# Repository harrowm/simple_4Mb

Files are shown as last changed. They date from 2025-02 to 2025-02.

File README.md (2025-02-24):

# simple_4Mb
A simple 4Mb RAM expansion card for the rosco sac.  Complicated only by the fact its mainly SMT ...

24th Feb 2025

The boards are back from jlcpcb.  The only potential issue is that I put the vias for the capacitors on the pad.  This seems to have worked by default without the expensive via in pad process.  The connections between the pads and VCC/GND check out ok.
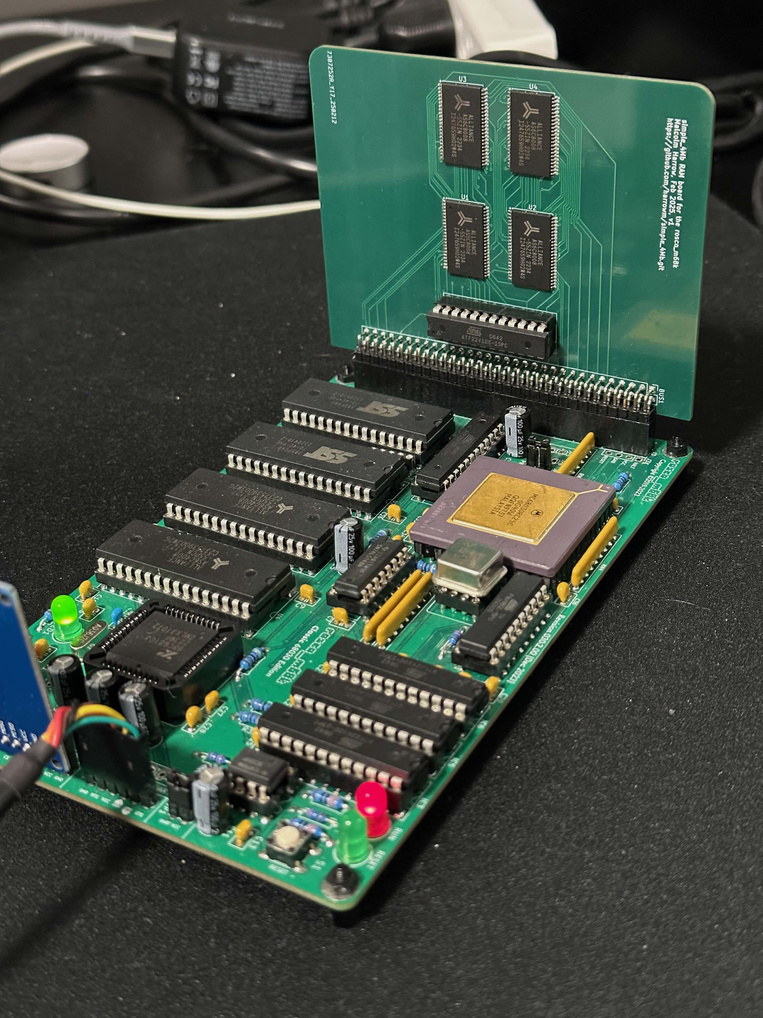
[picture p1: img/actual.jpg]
actual board


Running on the 68030 rosco works fine!
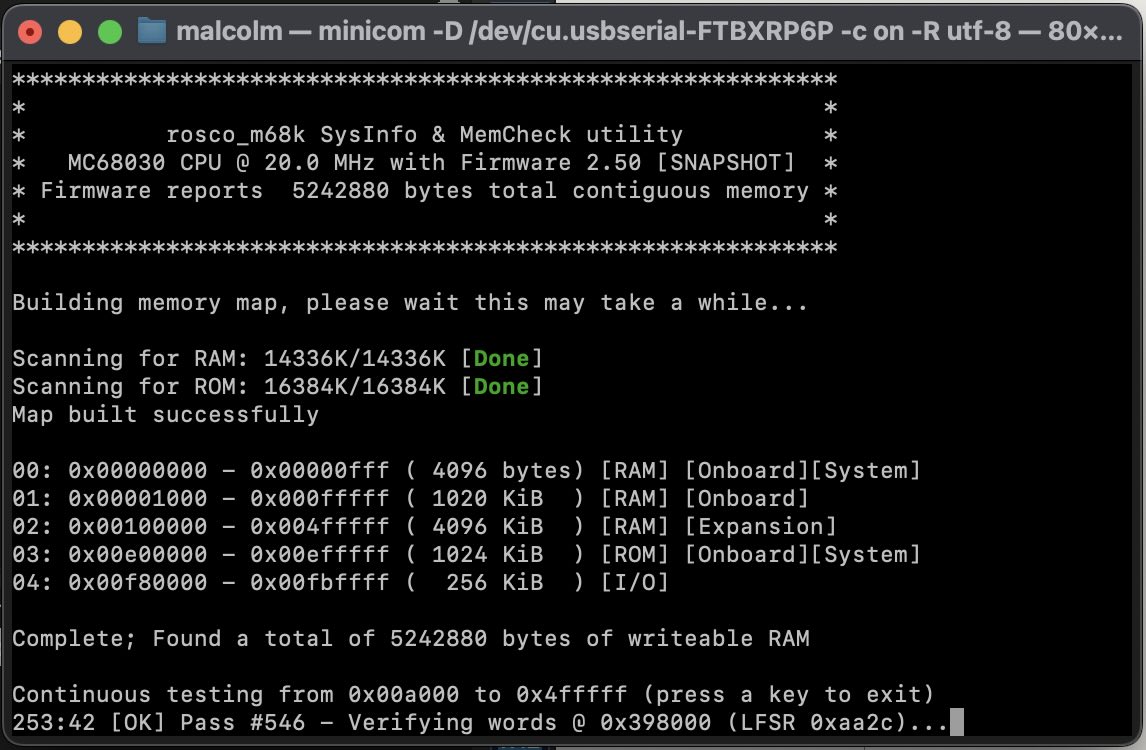
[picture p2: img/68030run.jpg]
running on the 68030


.. but the board is struggling on the 68010, not sure why ?
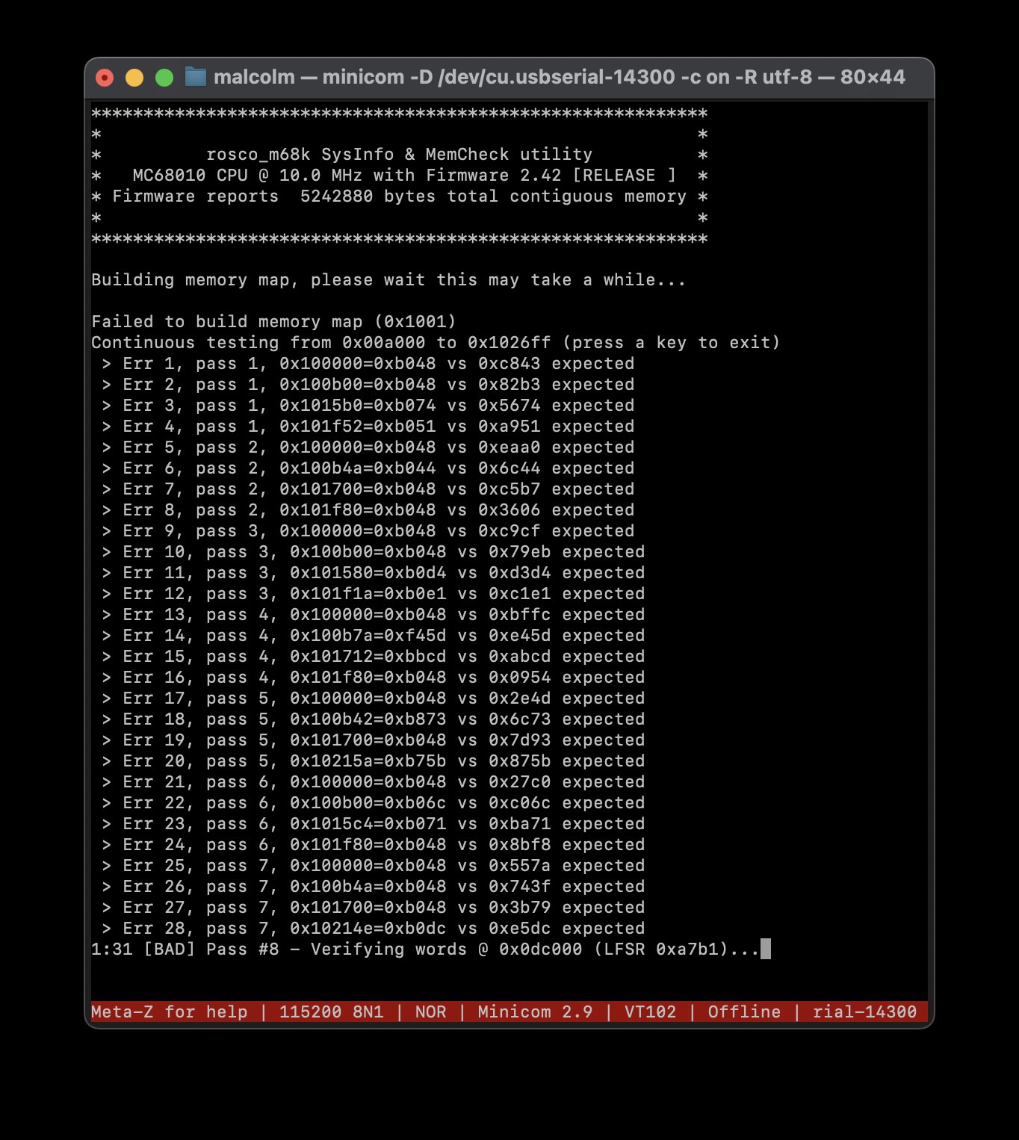
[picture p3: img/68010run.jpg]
running on the 68010


11th Feb 2025 - Sent to jlcpcb

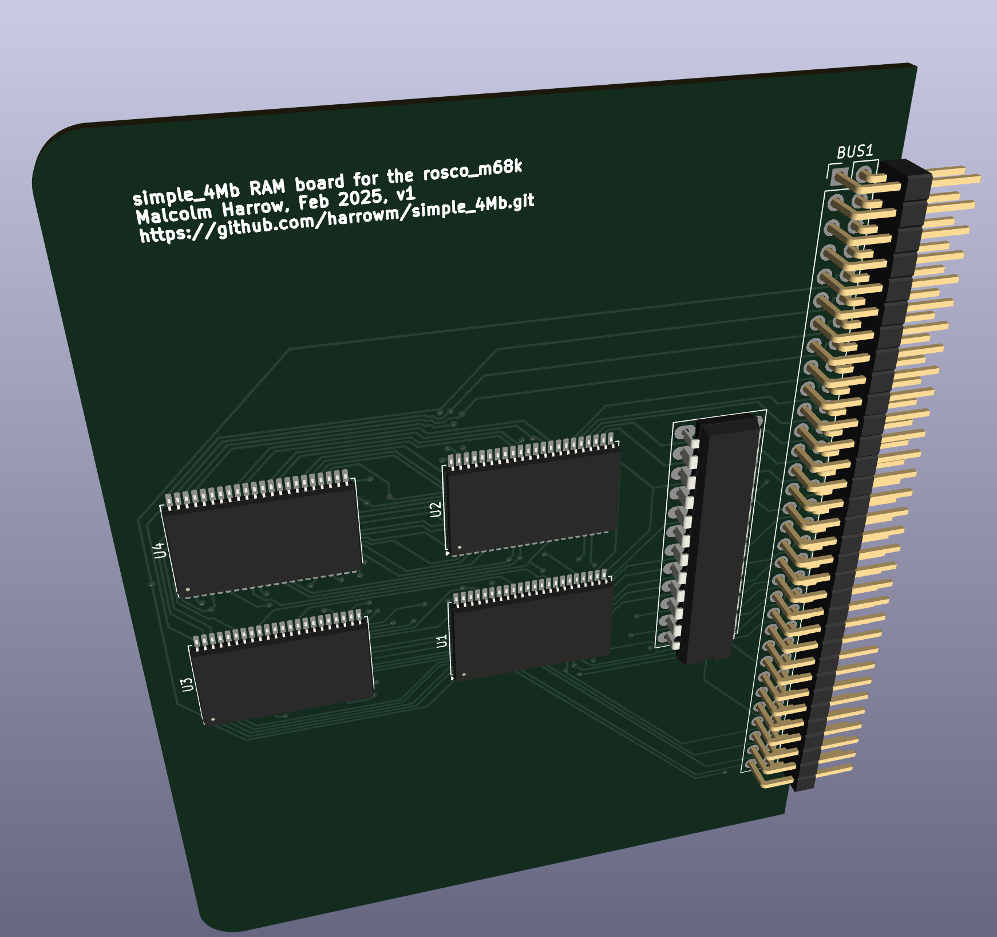
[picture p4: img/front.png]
3d model of board - front

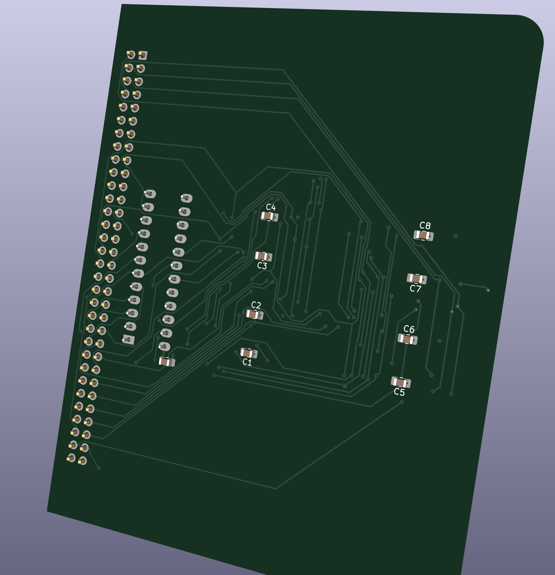
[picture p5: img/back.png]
3d model of board - back


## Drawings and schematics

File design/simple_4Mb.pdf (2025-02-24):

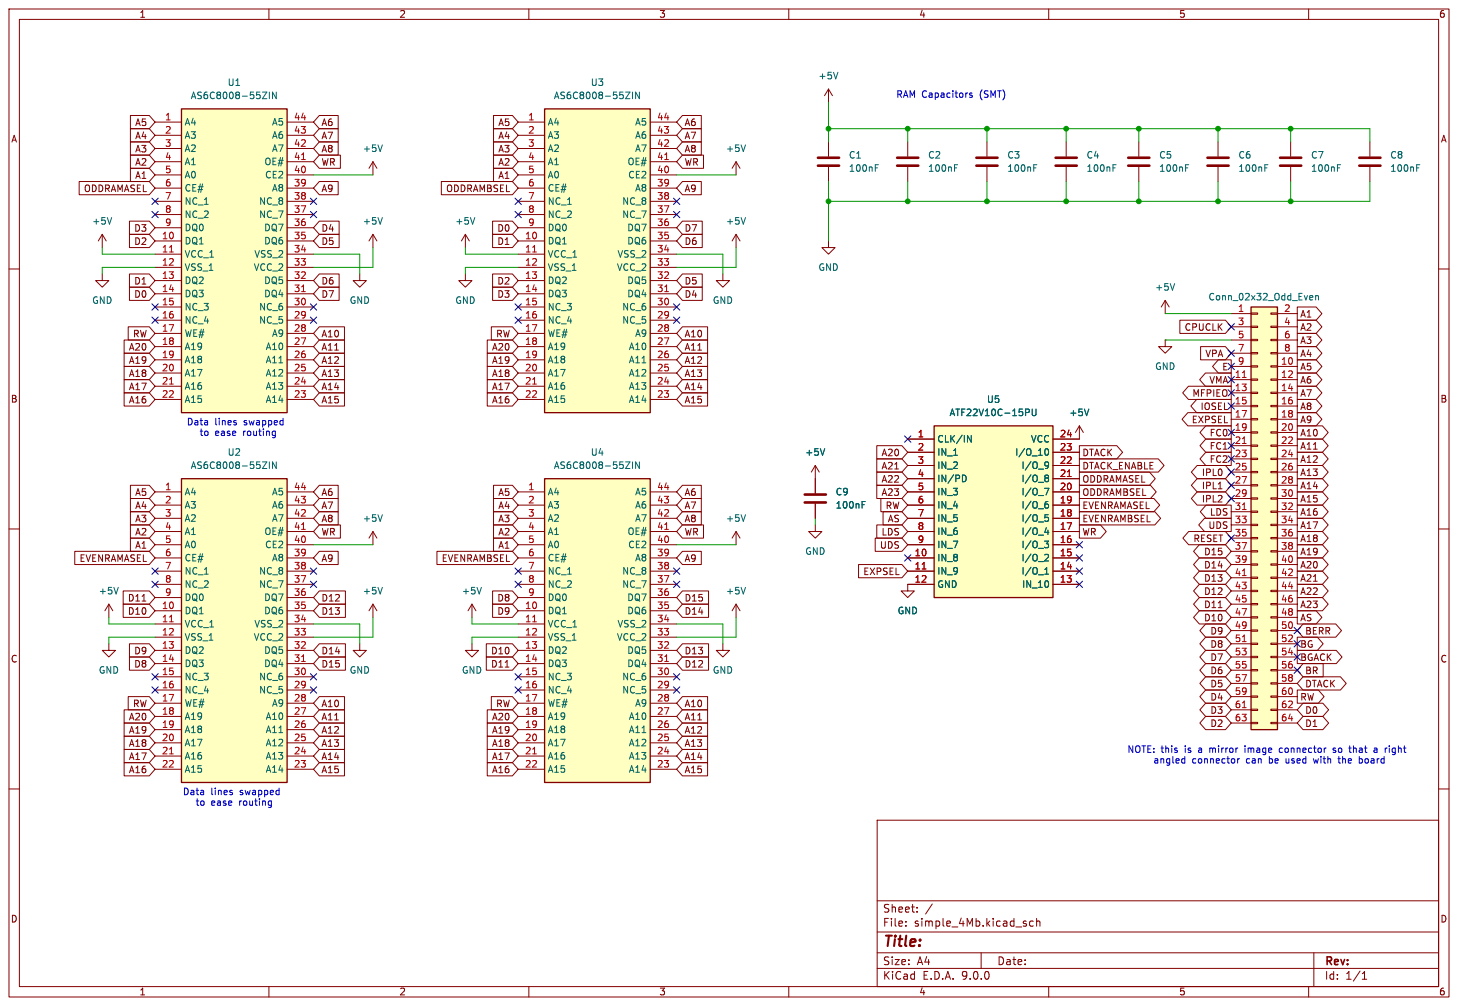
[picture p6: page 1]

Id: 1/1 Title: File: simple_4Mb.kicad_sch Sheet: /

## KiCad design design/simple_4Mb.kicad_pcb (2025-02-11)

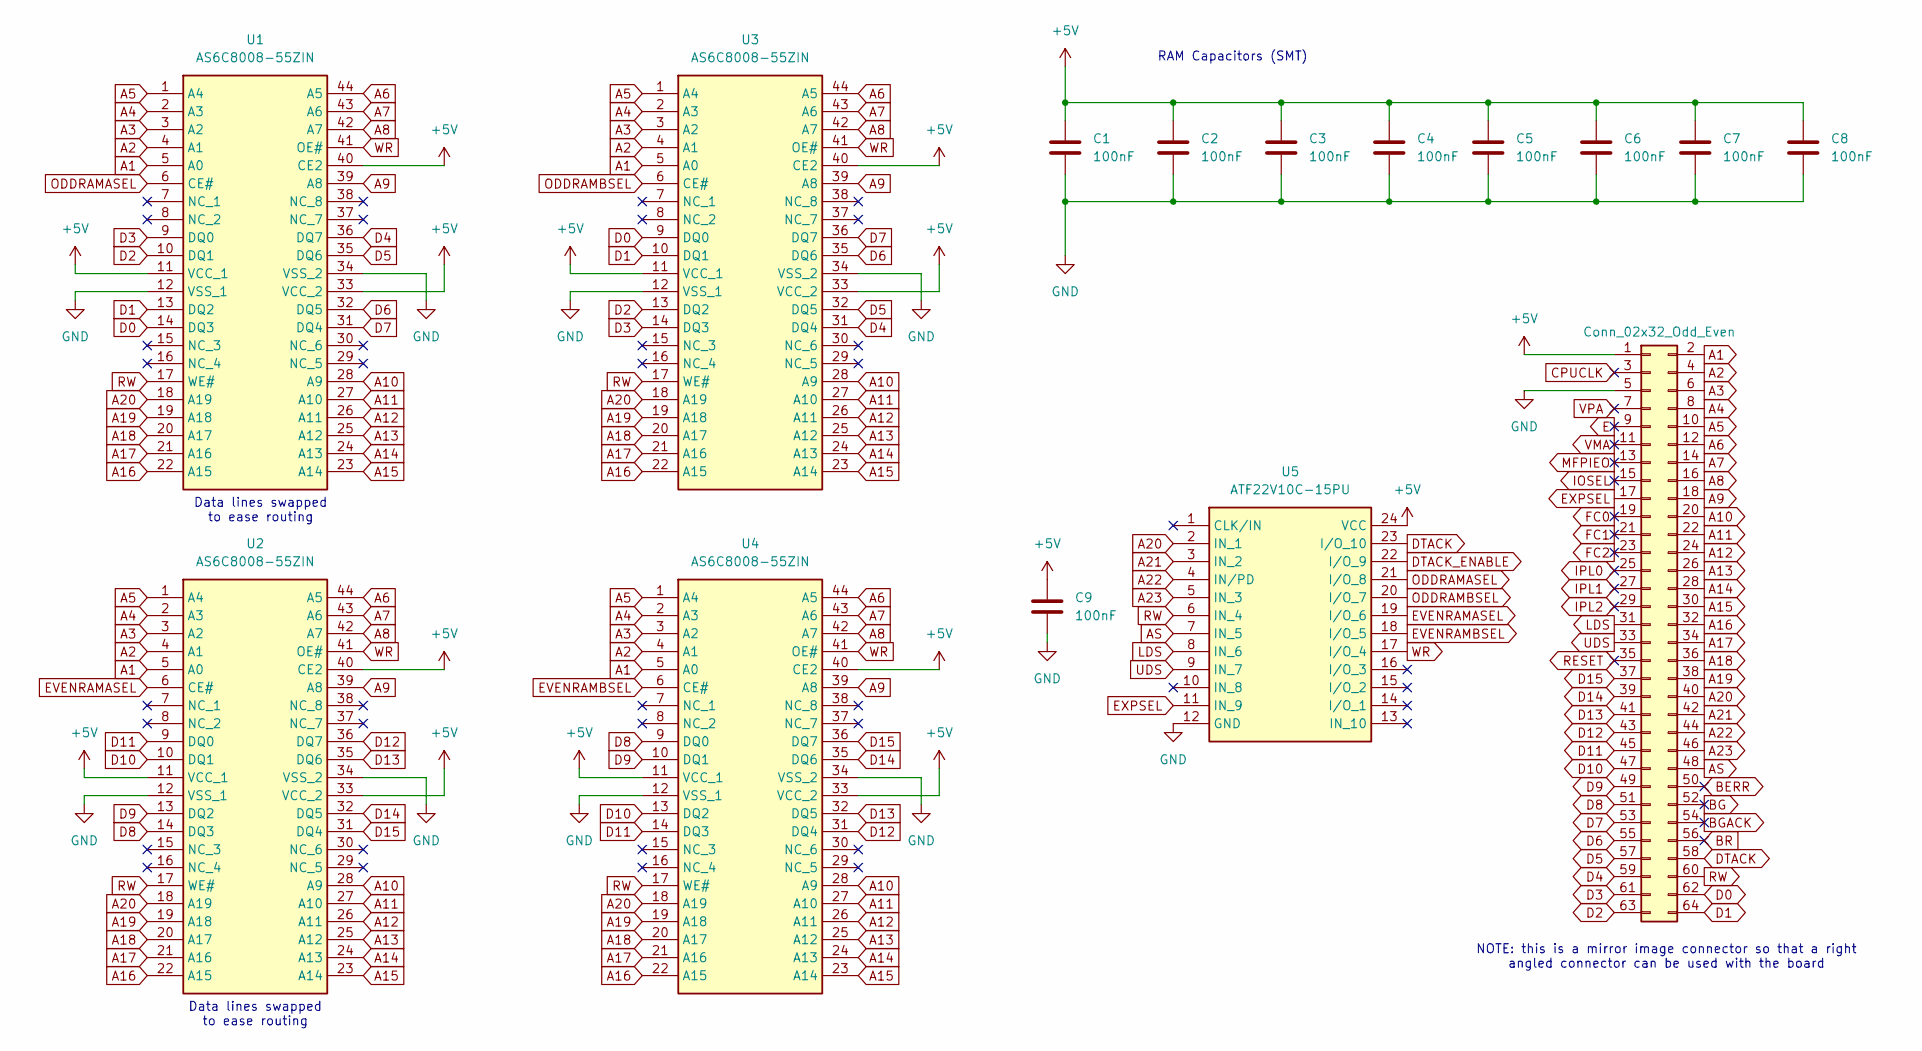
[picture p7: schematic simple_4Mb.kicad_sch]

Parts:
BUS1: Conn_02x32_Odd_Even; PinHeader_2x32_P2.54mm_Vertical
C1, C2, C3, C4, C5, C6, C7, C8, C9: 100nF; C_0805_2012Metric_Pad1.18x1.45mm_HandSolder
U1, U2, U3, U4: AS6C8008-55ZIN; TSOP-II-44_10.16x18.41mm_P0.8mm; Manufacturer_Part_Number AS6C8008-55ZIN; Mouser Part Number 913-AS6C8008-55ZIN
U5: ATF22V10C-15PU; DIP-24_W7.62mm_Socket_LongPads; Mouser Part Number 556-AF22V10C15PU

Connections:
+5V: BUS1.1, C1.1, C2.1, C3.1, C4.1, C5.1, C6.1, C7.1, C8.1, C9.1, U1.11 (VCC_1), U1.33 (VCC_2), U1.40 (CE2), U2.11 (VCC_1), U2.33 (VCC_2), U2.40 (CE2), U3.11 (VCC_1), U3.33 (VCC_2), U3.40 (CE2), U4.11 (VCC_1), U4.33 (VCC_2), U4.40 (CE2), U5.24 (VCC)
A1: BUS1.2, U1.5 (A0), U2.5 (A0), U3.5 (A0), U4.5 (A0)
A2: BUS1.4, U1.4 (A1), U2.4 (A1), U3.4 (A1), U4.4 (A1)
A3: BUS1.6, U1.3 (A2), U2.3 (A2), U3.3 (A2), U4.3 (A2)
A4: BUS1.8, U1.2 (A3), U2.2 (A3), U3.2 (A3), U4.2 (A3)
A5: BUS1.10, U1.1 (A4), U2.1 (A4), U3.1 (A4), U4.1 (A4)
A6: BUS1.12, U1.44 (A5), U2.44 (A5), U3.44 (A5), U4.44 (A5)
A7: BUS1.14, U1.43 (A6), U2.43 (A6), U3.43 (A6), U4.43 (A6)
A8: BUS1.16, U1.42 (A7), U2.42 (A7), U3.42 (A7), U4.42 (A7)
A9: BUS1.18, U1.39 (A8), U2.39 (A8), U3.39 (A8), U4.39 (A8)
A10: BUS1.20, U1.28 (A9), U2.28 (A9), U3.28 (A9), U4.28 (A9)
A11: BUS1.22, U1.27 (A10), U2.27 (A10), U3.27 (A10), U4.27 (A10)
A12: BUS1.24, U1.26 (A11), U2.26 (A11), U3.26 (A11), U4.26 (A11)
A13: BUS1.26, U1.25 (A12), U2.25 (A12), U3.25 (A12), U4.25 (A12)
A14: BUS1.28, U1.24 (A13), U2.24 (A13), U3.24 (A13), U4.24 (A13)
A15: BUS1.30, U1.23 (A14), U2.23 (A14), U3.23 (A14), U4.23 (A14)
A16: BUS1.32, U1.22 (A15), U2.22 (A15), U3.22 (A15), U4.22 (A15)
A17: BUS1.34, U1.21 (A16), U2.21 (A16), U3.21 (A16), U4.21 (A16)
A18: BUS1.36, U1.20 (A17), U2.20 (A17), U3.20 (A17), U4.20 (A17)
A19: BUS1.38, U1.19 (A18), U2.19 (A18), U3.19 (A18), U4.19 (A18)
A20: BUS1.40, U1.18 (A19), U2.18 (A19), U3.18 (A19), U4.18 (A19), U5.2 (IN_1)
A21: BUS1.42, U5.3 (IN_2)
A22: BUS1.44, U5.4 (IN/PD)
A23: BUS1.46, U5.5 (IN_3)
AS: BUS1.48, U5.7 (IN_5)
BERR: BUS1.50
BG: BUS1.52
BGACK: BUS1.54
BR: BUS1.56
CPUCLK: BUS1.3
D0: BUS1.62, U1.14 (DQ3), U3.9 (DQ0)
D1: BUS1.64, U1.13 (DQ2), U3.10 (DQ1)
D2: BUS1.63, U1.10 (DQ1), U3.13 (DQ2)
D3: BUS1.61, U1.9 (DQ0), U3.14 (DQ3)
D4: BUS1.59, U1.36 (DQ7), U3.31 (DQ4)
D5: BUS1.57, U1.35 (DQ6), U3.32 (DQ5)
D6: BUS1.55, U1.32 (DQ5), U3.35 (DQ6)
D7: BUS1.53, U1.31 (DQ4), U3.36 (DQ7)
D8: BUS1.51, U2.14 (DQ3), U4.9 (DQ0)
D9: BUS1.49, U2.13 (DQ2), U4.10 (DQ1)
D10: BUS1.47, U2.10 (DQ1), U4.13 (DQ2)
D11: BUS1.45, U2.9 (DQ0), U4.14 (DQ3)
D12: BUS1.43, U2.36 (DQ7), U4.31 (DQ4)
D13: BUS1.41, U2.35 (DQ6), U4.32 (DQ5)
D14: BUS1.39, U2.32 (DQ5), U4.35 (DQ6)
D15: BUS1.37, U2.31 (DQ4), U4.36 (DQ7)
DTACK: BUS1.58, U5.23 (I/O_10)
DTACK_ENABLE: U5.22 (I/O_9)
E: BUS1.9
EVENRAMASEL: U2.6 (CE#), U5.19 (I/O_6)
EVENRAMBSEL: U4.6 (CE#), U5.18 (I/O_5)
EXPSEL: BUS1.17, U5.11 (IN_9)
FC0: BUS1.19
FC1: BUS1.21
FC2: BUS1.23
GND: BUS1.5, C1.2, C2.2, C3.2, C4.2, C5.2, C6.2, C7.2, C8.2, C9.2, U1.12 (VSS_1), U1.34 (VSS_2), U2.12 (VSS_1), U2.34 (VSS_2), U3.12 (VSS_1), U3.34 (VSS_2), U4.12 (VSS_1), U4.34 (VSS_2), U5.12 (GND)
IOSEL: BUS1.15
IPL0: BUS1.25
IPL1: BUS1.27
IPL2: BUS1.29
LDS: BUS1.31, U5.8 (IN_6)
MFPIEO: BUS1.13
ODDRAMASEL: U1.6 (CE#), U5.21 (I/O_8)
ODDRAMBSEL: U3.6 (CE#), U5.20 (I/O_7)
RESET: BUS1.35
RW: BUS1.60, U1.17 (WE#), U2.17 (WE#), U3.17 (WE#), U4.17 (WE#), U5.6 (IN_4)
UDS: BUS1.33, U5.9 (IN_7)
VMA: BUS1.11
VPA: BUS1.7
WR: U1.41 (OE#), U2.41 (OE#), U3.41 (OE#), U4.41 (OE#), U5.17 (I/O_4)

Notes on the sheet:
NOTE: this is a mirror image connector so that a right angled connector can be used with the board
Data lines swapped to ease routing
RAM Capacitors (SMT)

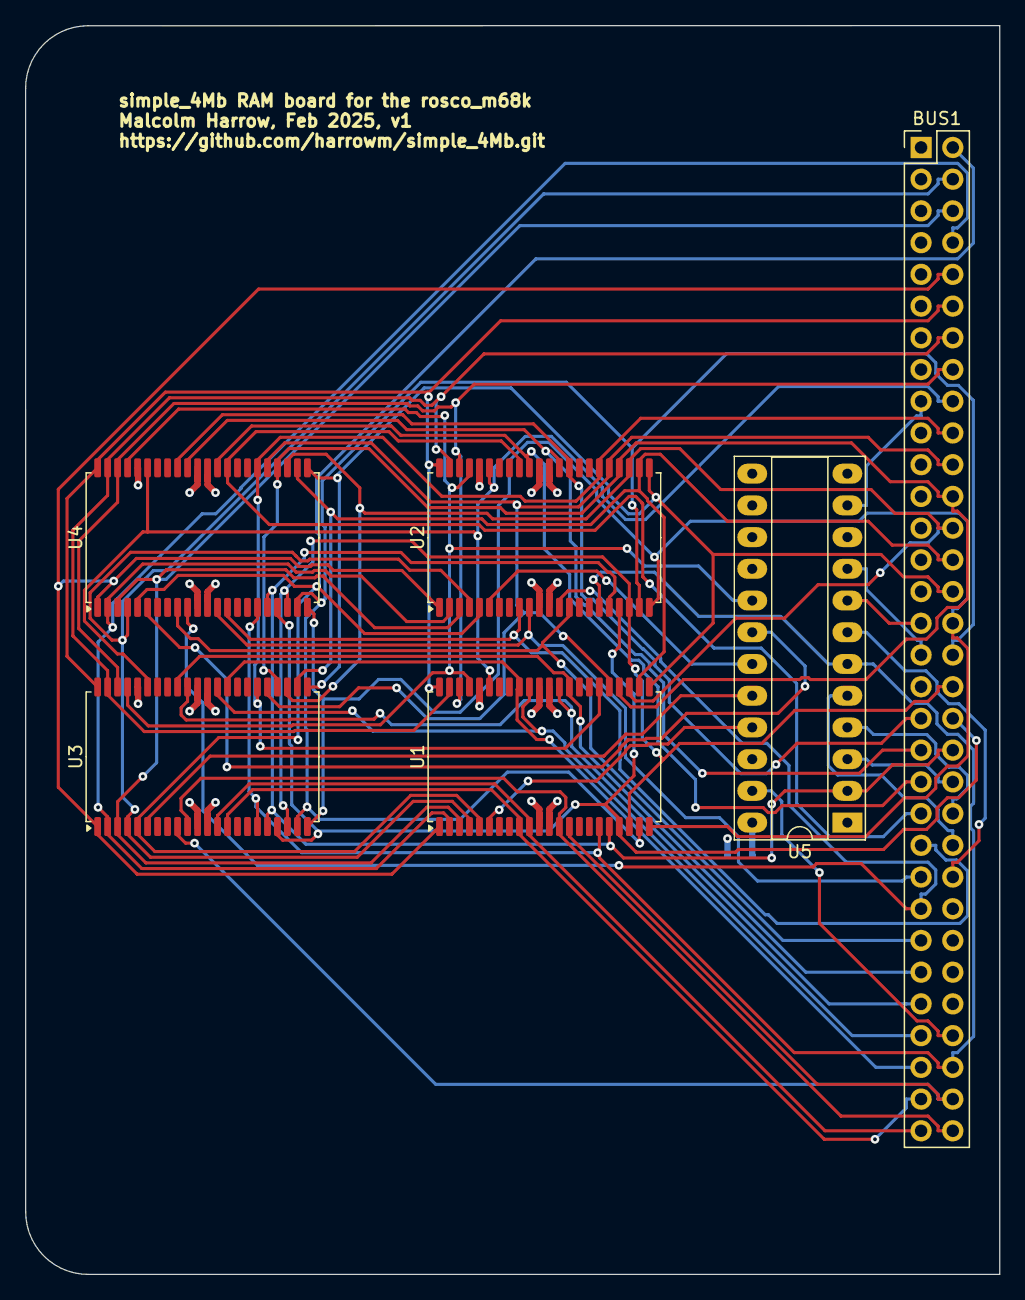
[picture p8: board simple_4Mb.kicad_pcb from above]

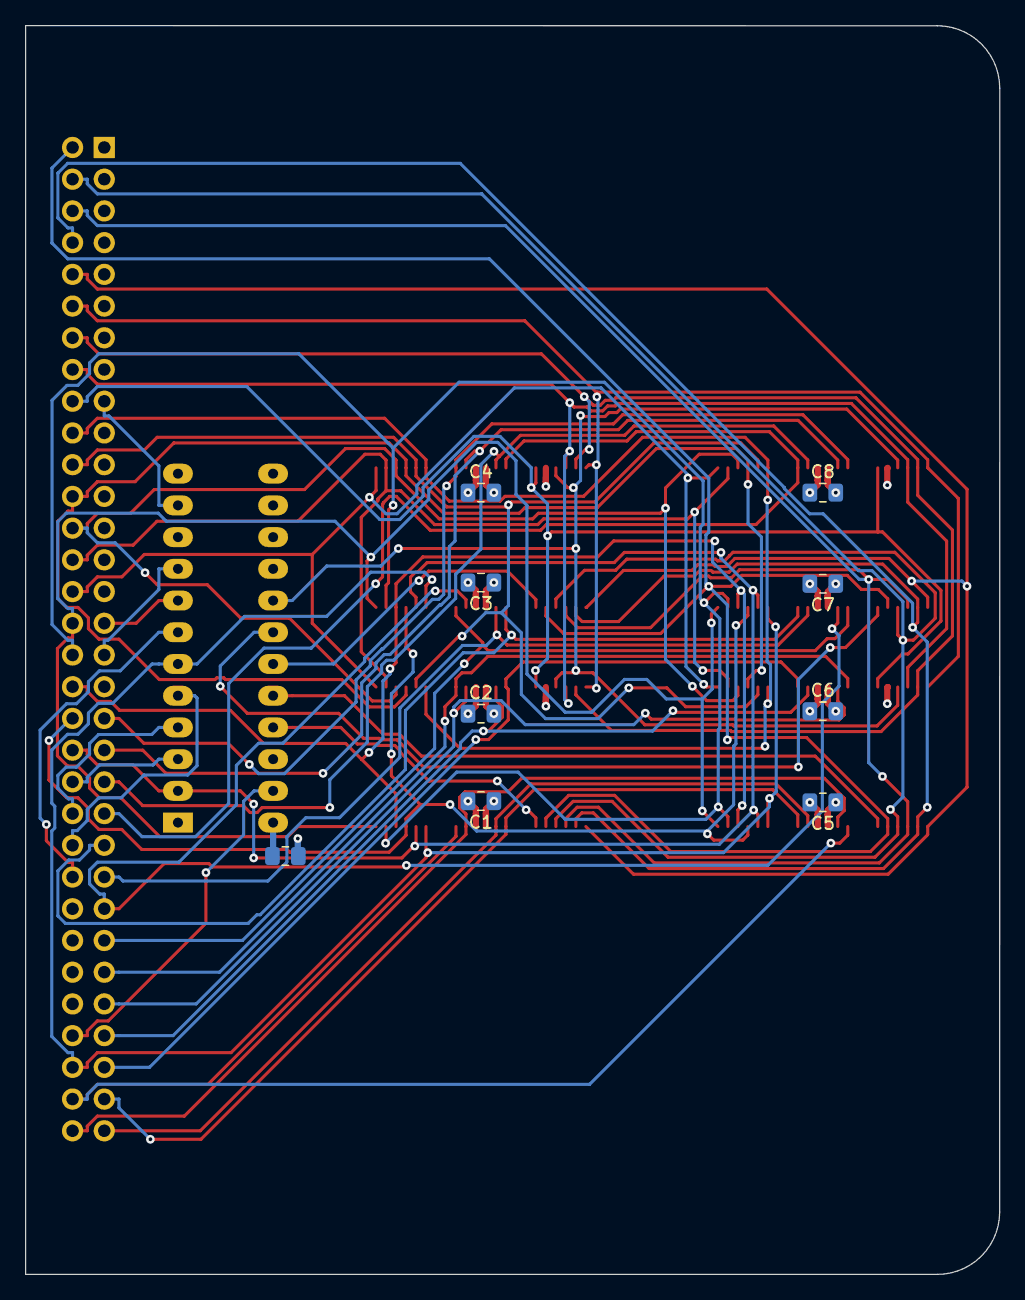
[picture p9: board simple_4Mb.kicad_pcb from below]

Board: 4 copper layers, 78.0 x 100.0 mm, 15 parts (9 on the bottom side), 52 nets.

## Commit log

2025-02-11 Initial board design
    [simple_4Mb.kicad_pcb, simple_4Mb.kicad_sch]
2025-02-11 Add datasheet for memory and production data
    [simple_4Mb.kicad_pcb]
2025-02-11 Update readme images
    [simple_4Mb.kicad_pcb]
